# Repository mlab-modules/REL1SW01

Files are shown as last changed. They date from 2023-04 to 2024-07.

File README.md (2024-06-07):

# REL1SW01 - One Relay and/or Two N-MOSFET

## Introduction
The REL1SW01 is a versatile module from the MLAB series designed for triggering high current demaining devices (eg. high power led, high voltage circuits, DC motors, ..) using two N-MOSFET transistors or relay. It supports both bistable and monostable relay configurations and can be integrated into various electronic projects requiring relay switching or direct MOSFET control.

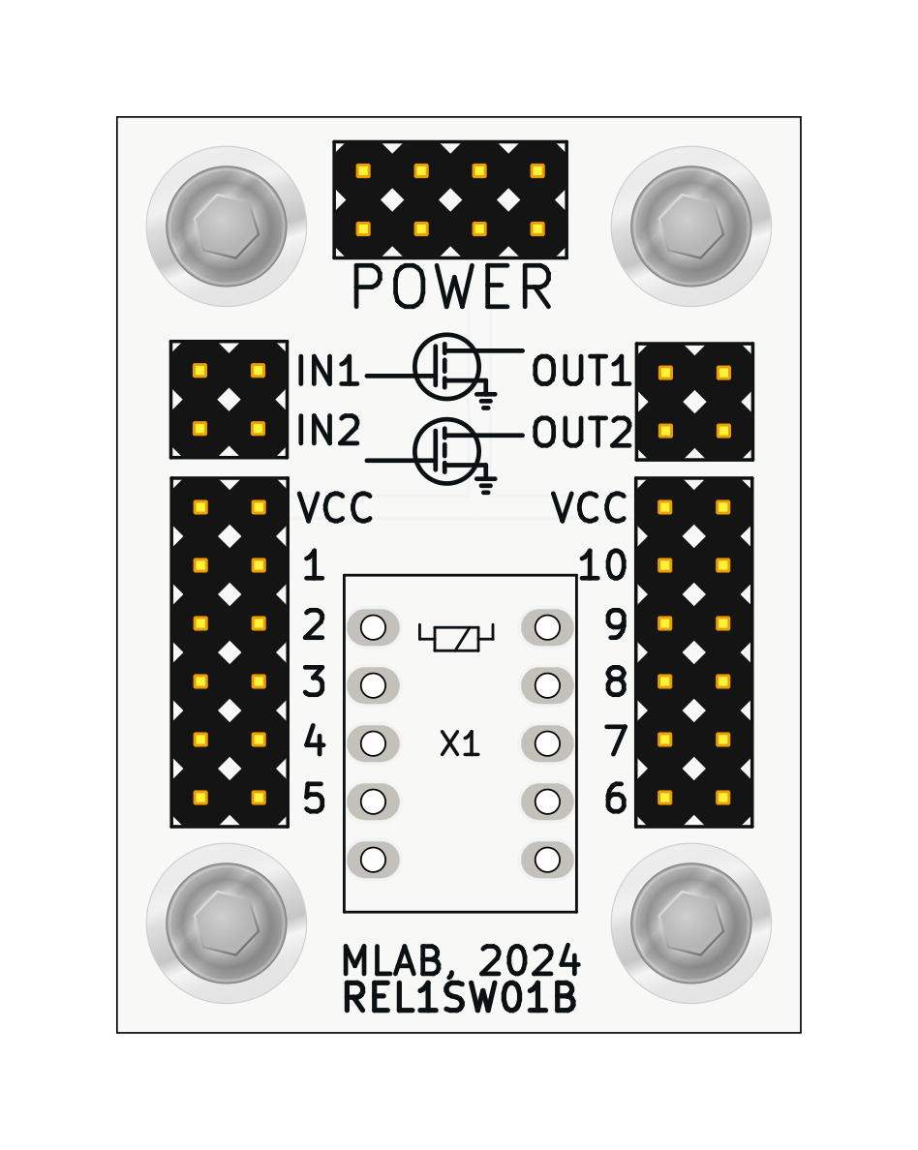
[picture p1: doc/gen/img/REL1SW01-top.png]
REL1SW01A


## Features
- Equipped with two N-MOSFET transistors (IRLML6244).
  - Capable of switching voltages up to 20V.
- Supports optional relay addition (e.g., DPDT FRT5).
- Configurable for either relay coil driving or independent transistor switching.
- Compatible with MCU control.

## Specifications
### MOSFET Transistors (IRLML6244)
- **Drain-Source Voltage (Vds):** 20V
- **Gate-Source Voltage (Vgs):** ±12V
- **Continuous Drain Current (Id):** 6.3A
- **Total Power Dissipation (Pd):** 1.3W
- **Gate Threshold Voltage (Vgs(th)):** 1.1V
- **On-State Resistance (Rds(on)):** 21mΩ at Vgs = 4.5V

## Usage
### Without Relay
- Connect the load to the drain of the MOSFET.
- The source of the MOSFET should be connected to GND.
- Use the gate to control switching via the MCU.

### With Relay
- Connect the relay's coil terminals to the MOSFETs as per the required configuration.
- The relay contacts will then be used to switch the external load.

## Configuration
To configure the module for different uses:
1. For direct MOSFET switching, connect the load between the drain and the positive supply (VCC).
2. For relay operation, connect the relay coil to the designated pins controlled by the MOSFETs.

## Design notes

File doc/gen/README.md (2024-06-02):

# PCB

Board size: 29.97x40.13 mm (1.18x1.58 inches)

- This is the size of the rectangle that contains the board
- Thickness: 1.6 mm (63 mils)
- Material: FR4
- Finish: HAL
- Layers: 2
- Copper thickness: 35 µm

Solder mask: TOP / BOTTOM

- Color: Green

Silk screen: TOP / BOTTOM

- Color: White

# Important sizes

Clearance: 0.15 mm (6 mils)

Track width: 0.5 mm (20 mils)

- By design rules: 0.0 mm (0 mils)

Drill: 1.0 mm (39 mils)

- Vias: N/A mm (N/A mils) [Design: 0.4 mm (16 mils)]
- Pads: 1.0 mm (39 mils)
- The above values are real drill sizes, they add 0.1 mm (4 mils) to plated holes (PTH)

Via: N/A/N/A mm (N/A/N/A mils)

- By design rules: 0.5/0.3 mm (20/12 mils)
- Micro via: yes [0.2/0.1 mm (8/4 mils)]
- Buried/blind via: yes
- Total: 0 (thru: 0 buried/blind: 0 micro: 0)

Outer Annular Ring: 0.25 mm (10 mils)

- By design rules: 0.25 mm (10 mils)

Eurocircuits class: 6A
- Using min drill 1.0 mm for an OAR of 0.25 mm

# General stats

Components count: (SMD/THT)

- Top: 0/10 (THT)
- Bottom: 12/0 (SMD)

Defined tracks:

- 0.25 mm (10 mils)
- 0.5 mm (20 mils)

Used tracks:

- 0.5 mm (20 mils) (14) defined: yes
- 0.8 mm (31 mils) (56) defined: no

Defined vias:

Used vias:

Holes (excluding vias):

- 0.89 mm (35 mils) (40)
- 1.0 mm (39 mils) (10)
- 3.0 mm (118 mils) (4)

Oval holes:

Drill tools (including vias and computing adjusts and rounding):

- 1.0 mm (39 mils) (40)
- 1.1 mm (43 mils) (10)
- 3.1 mm (122 mils) (4)

Solder paste stats:

Using a paste with 87.75 % alloy, that has an specific gravity for the alloy of 7.4 g/cm³
and 1.0 g/cm³ for the flux. This paste has an specific gravity of  4.15 g/cm³.

The stencil thickness is  0.12 mm.

| Side | Pads with paste | Area [mm²] | Paste [g] |
|---|---|---|---|
| Total  | 26 | 57.29 | 0.29 |

Note: this is just an approximation to the theoretical value. Margins of the solder mask and waste aren't computed.

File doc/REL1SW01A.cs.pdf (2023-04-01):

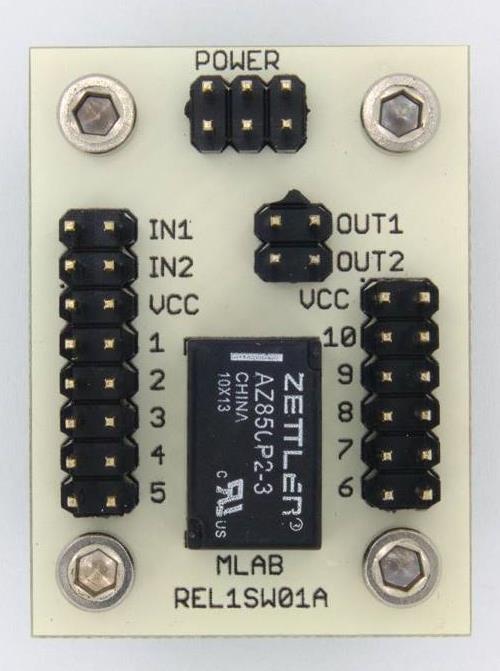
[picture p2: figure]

REL1SW01A / 2016-03-09 / jacho / http://www.mlab.cz | 1 / 4
REL1SW01A | MLAB

# Relé se dvěma tranzsitory

Jan Chroust

### Modul je určen pro spínání relé pomocí procesoru, nebo je možné

využít samostatně dva NMOSFETy.

# 1. Technické parametry

Parametr | Hodnota | Poznámka
Napájení | Dle relé | (Relé A-5V, AZ850 + další)
Využití | 1xrelé, 2xNMOSFET
Rozměry | 29.97 x 40.13 x 16 mm | Výška nad základní deskou

REL1SW01A | MLAB

# 2. Popis konstrukce

## 2.1. Úvod

Modul byl navržen jako univerzální patice pro jedno relé (je možné osadit relé řady A-5V, AZ850 + další pasující). Dva tranzistory umožňují ovládat až dvě cívky procesorem. Je možné využít modul jen jako tranzistorový spínač.

## 2.2. Zapojení

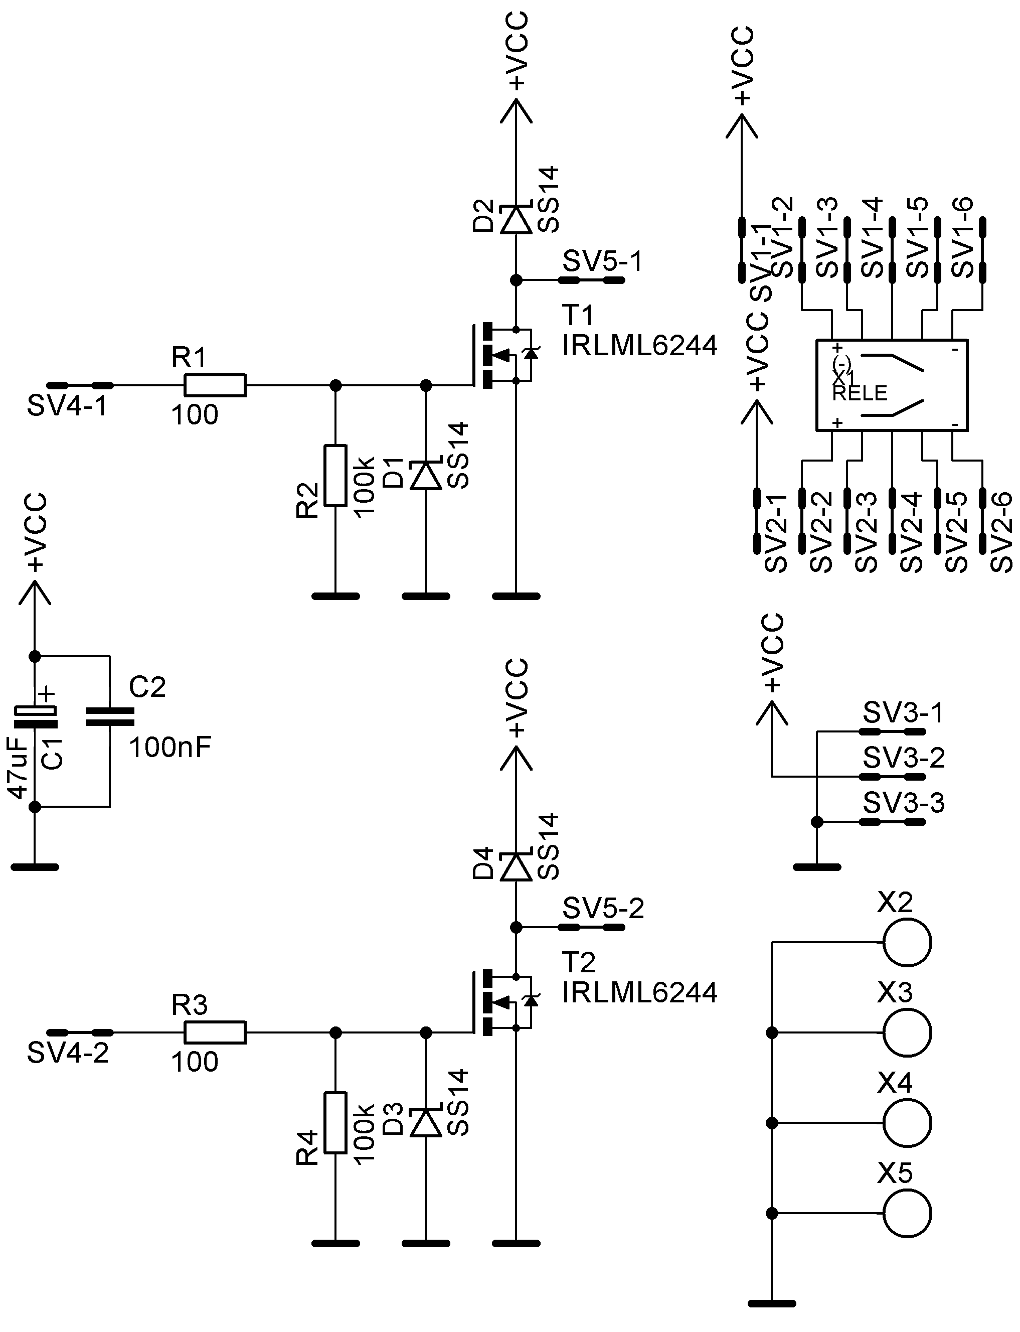
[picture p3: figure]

REL1SW01A | MLAB

# 3. Osazení a oživení

## 3.1. Osazení

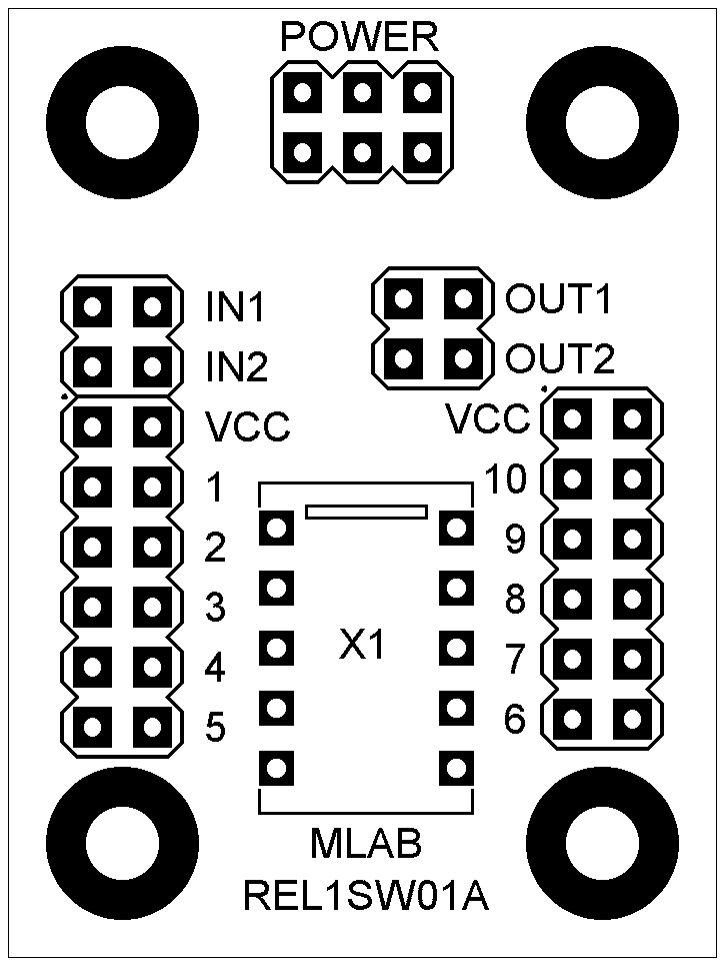
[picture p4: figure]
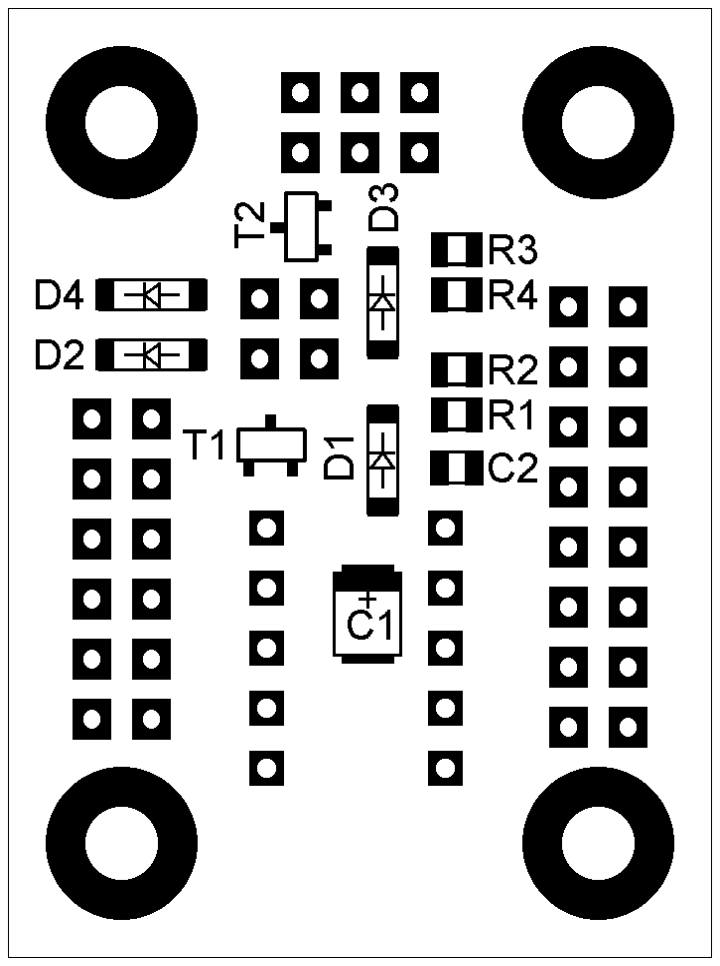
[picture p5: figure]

Označení | Typ (pouzdro)
C1 | 47uF (B)
C2 | 100nF (0805)
D1 - D4 | SS14 (SMA)
R1 ,R3 | 100 (0805)
R2, R4 | 100k (0805)
SV1, SV2 | JUMP2X6
SV3 | JUMP2X3
SV4, SV5 | JUMP2X2
T1, T2 | IRLML6244 (SOT23)
X1 | AZ850P2-3
X2 - X5 | Šroub M3

## 3.2. Oživení

Po osazení modulu je dobré provést vizuální kontrolu, případně proměřit, zda na napájení není zkrat. Další oživení není potřeba.

REL1SW01A | MLAB

Popis základního zapojení modulu s relé AZ850P2-3 (bistabilní) pro připojení k procesoru:
- připojte napájení na hřebínek POWER (Pro AZ850P2-3 stačí 3V)
- mínus pól (pin 5 pro AZ850P2) nastavovací cívky propojte vodičem na OUT1
- mínus pól (pin 6 pro AZ850P2) resetovací cívky propojte vodičem na OUT2
- kladný pól (pin 1 pro AZ850P2) nastavovací cívky propojte vodičem na VCC
- kladný pól (pin 10 pro AZ850P2) resetovací cívky propojte vodičem na VCC
- řídící signály se přivádějí na IN1 (pro nastavovací cívku u AZ850P2-3) a IN2 (pro resetovací cívku u AZ850P2-3)
- Přivedením kladného pulzu na IN1 dojde k přepnutí relé do jedné polohy. Pro přepnutí do druhé polohy se přivede kladný pulz na IN2. (Relé AZ850P2-3 je bistabilní. To znamená, že pro udržení polohy relé, není potřeba udržovat napětí na cívce.)

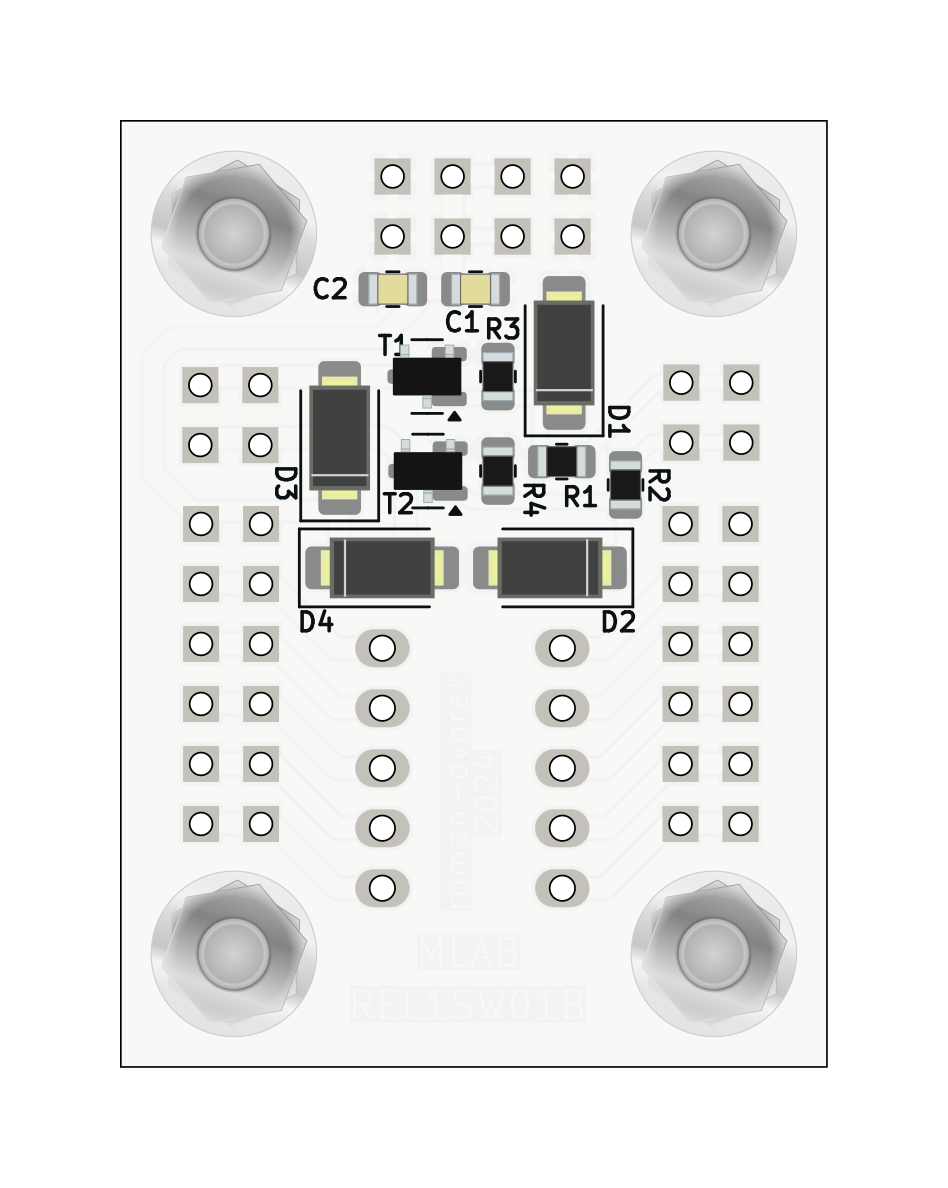
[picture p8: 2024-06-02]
doc/gen/img/REL1SW01-bottom.png

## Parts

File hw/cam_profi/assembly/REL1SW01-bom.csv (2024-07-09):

Component | Description | Part | References | Value | Footprint | Quantity Per PCB | Datasheet | ust_id
1 | Unpolarized capacitor, small symbol | C_Small | C2 | 100nF | C_0805_2012Metric | 1 | ~ | 5c70984712875079b91f8b4c
2 | Unpolarized capacitor, small symbol | C_Small | C1 | 47uF | C_0805_2012Metric | 1 | ~ | 60d580ff1287500165f8595a
3 | 40V 1A Schottky Diode, SMA | SS14 | D1D2D3D4 | SS14 | D_SMA | 4 | https://www.vishay.com/docs/88746/ss12.pdf | 5c70984512875079b91f88bd
4 |  | R0805 | R1R2 | 100R | R_0805_2012Metric | 2 |  | 5c70984512875079b91f8977
5 |  | R0805 | R3R4 | 100k | R_0805_2012Metric | 2 |  | 639ed3d540d28a66c9e88a9e
6 |  | IRLML6244TRPBF | T1T2 | IRLML6244 | SOT-23 | 2 |  | 5c70984712875079b91f8aef
7 |  | RELE | X1 | RELE | Relay_DPDT_FRT5 | 1

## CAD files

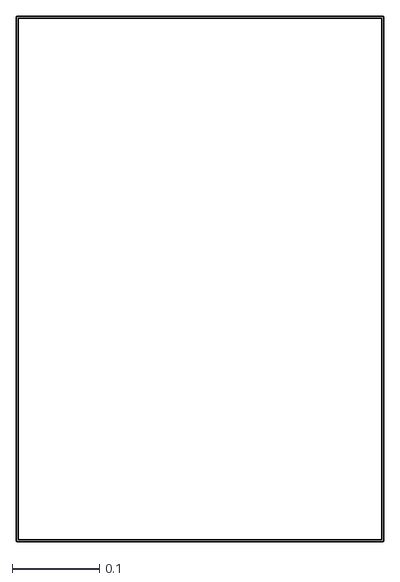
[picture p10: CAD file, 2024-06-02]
doc/gen/dxf/REL1SW01-F_Courtyard.dxf
0.421 x 0.602

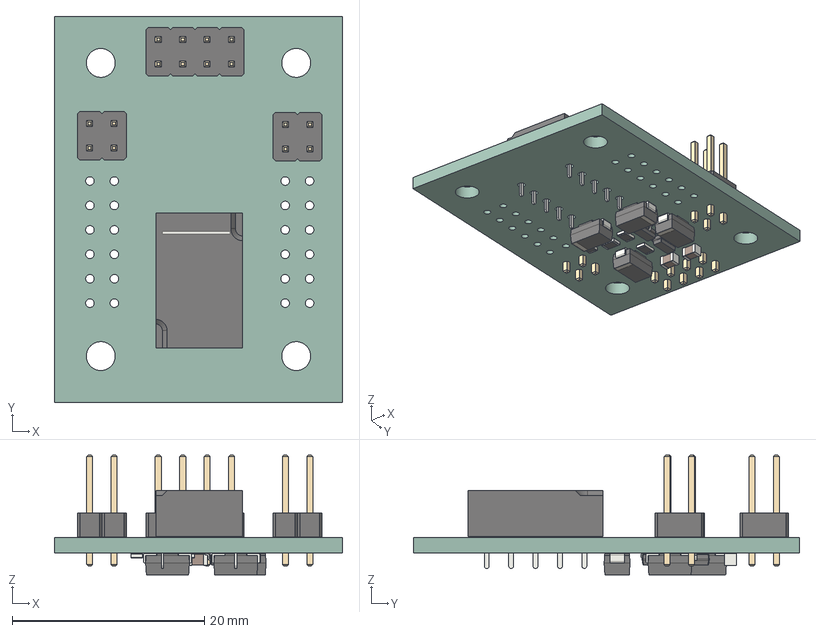
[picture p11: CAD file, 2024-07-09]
doc/gen/REL1SW01.step
30.0 x 40.1 x 12.5 mm
Relay_DPDT_FRT5
PinHeader_2x04_P254mm_Vertical
PinHeader_2x02_P254mm_Vertical x 2
R_0805_2012Metric x 4
SOT_23 x 2
D_SMA x 4
C_0805_2012Metric x 2
kibot_hpxaq1g5 PCB

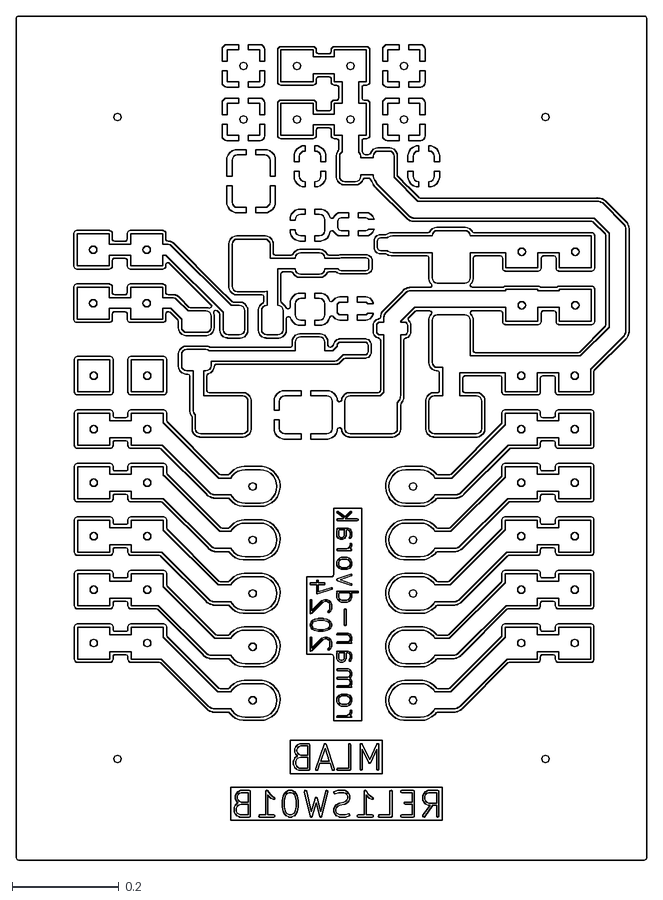
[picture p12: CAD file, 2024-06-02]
doc/gen/dxf/REL1SW01-B_Cu.dxf
1.18 x 1.58

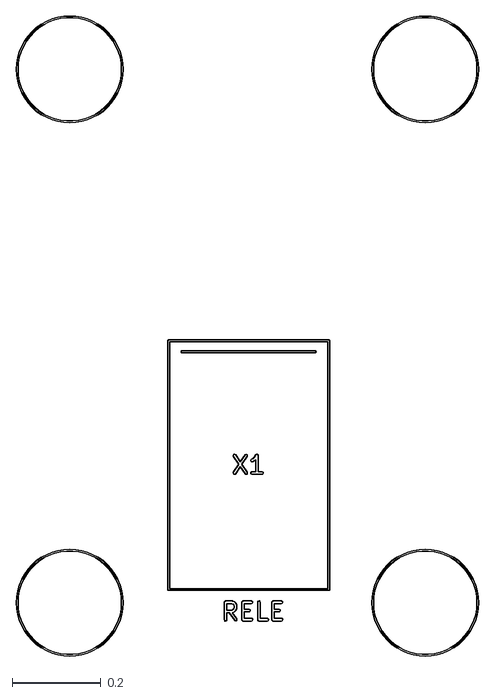
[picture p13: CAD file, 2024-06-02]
doc/gen/dxf/REL1SW01-F_Fab.dxf
1.04 x 1.44

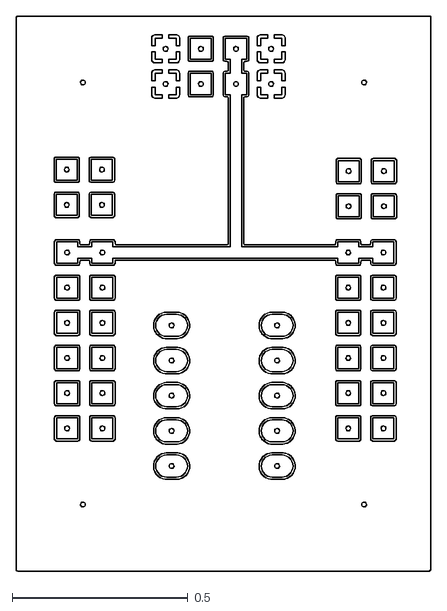
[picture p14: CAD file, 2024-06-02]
doc/gen/dxf/REL1SW01-F_Cu.dxf
1.18 x 1.58

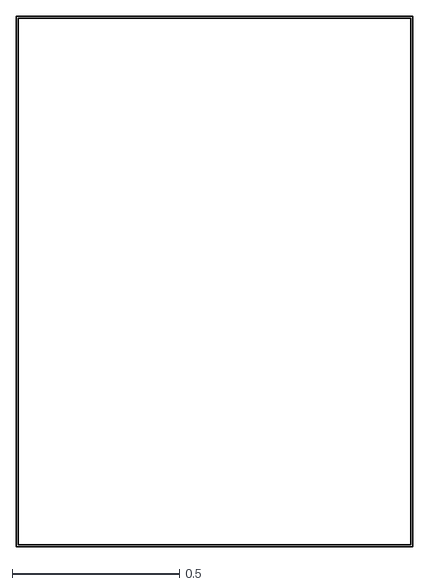
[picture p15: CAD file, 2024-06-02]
doc/gen/dxf/REL1SW01-Edge_Cuts.dxf
1.19 x 1.59

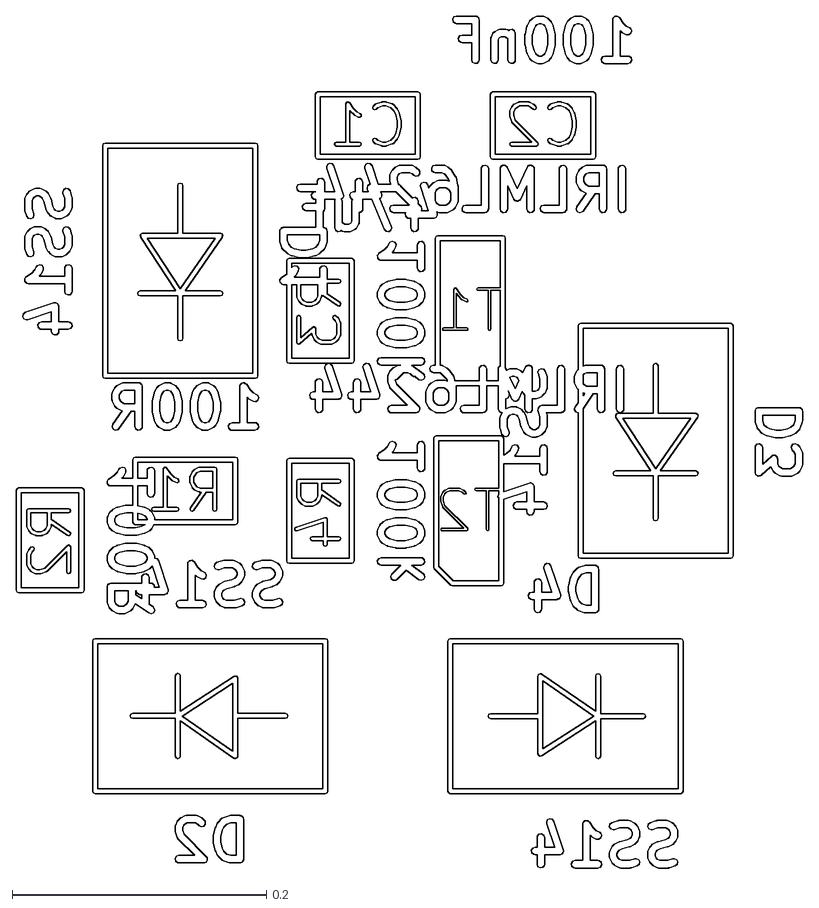
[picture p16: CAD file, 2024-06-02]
doc/gen/dxf/REL1SW01-B_Fab.dxf
0.619 x 0.67

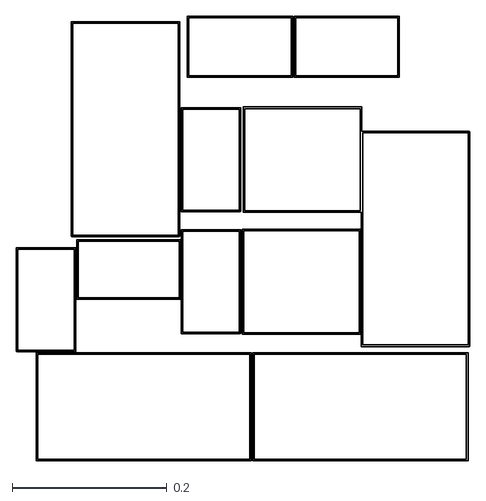
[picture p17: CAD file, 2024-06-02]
doc/gen/dxf/REL1SW01-B_Courtyard.dxf
0.585 x 0.574

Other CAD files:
doc/gen/dxf/REL1SW01-User_3.dxf
doc/gen/dxf/REL1SW01-Margin.dxf
doc/gen/dxf/REL1SW01-User_7.dxf
doc/gen/dxf/REL1SW01-User_4.dxf
doc/gen/dxf/REL1SW01-User_6.dxf
doc/gen/dxf/REL1SW01-User_9.dxf
doc/gen/dxf/REL1SW01-User_2.dxf
doc/gen/dxf/REL1SW01-User_5.dxf
doc/gen/dxf/REL1SW01-User_Comments.dxf
doc/gen/dxf/REL1SW01-F_Adhesive.dxf
doc/gen/dxf/REL1SW01-B_Adhesive.dxf
doc/gen/dxf/REL1SW01-B_Mask.dxf
doc/gen/dxf/REL1SW01-B_Paste.dxf
doc/gen/dxf/REL1SW01-B_Silkscreen.dxf
doc/gen/dxf/REL1SW01-F_Mask.dxf
doc/gen/dxf/REL1SW01-F_Paste.dxf
doc/gen/dxf/REL1SW01-F_Silkscreen.dxf
doc/gen/dxf/REL1SW01-User_1.dxf
doc/gen/dxf/REL1SW01-User_8.dxf
doc/gen/dxf/REL1SW01-User_Drawings.dxf
doc/gen/dxf/REL1SW01-User_Eco1.dxf
doc/gen/dxf/REL1SW01-User_Eco2.dxf

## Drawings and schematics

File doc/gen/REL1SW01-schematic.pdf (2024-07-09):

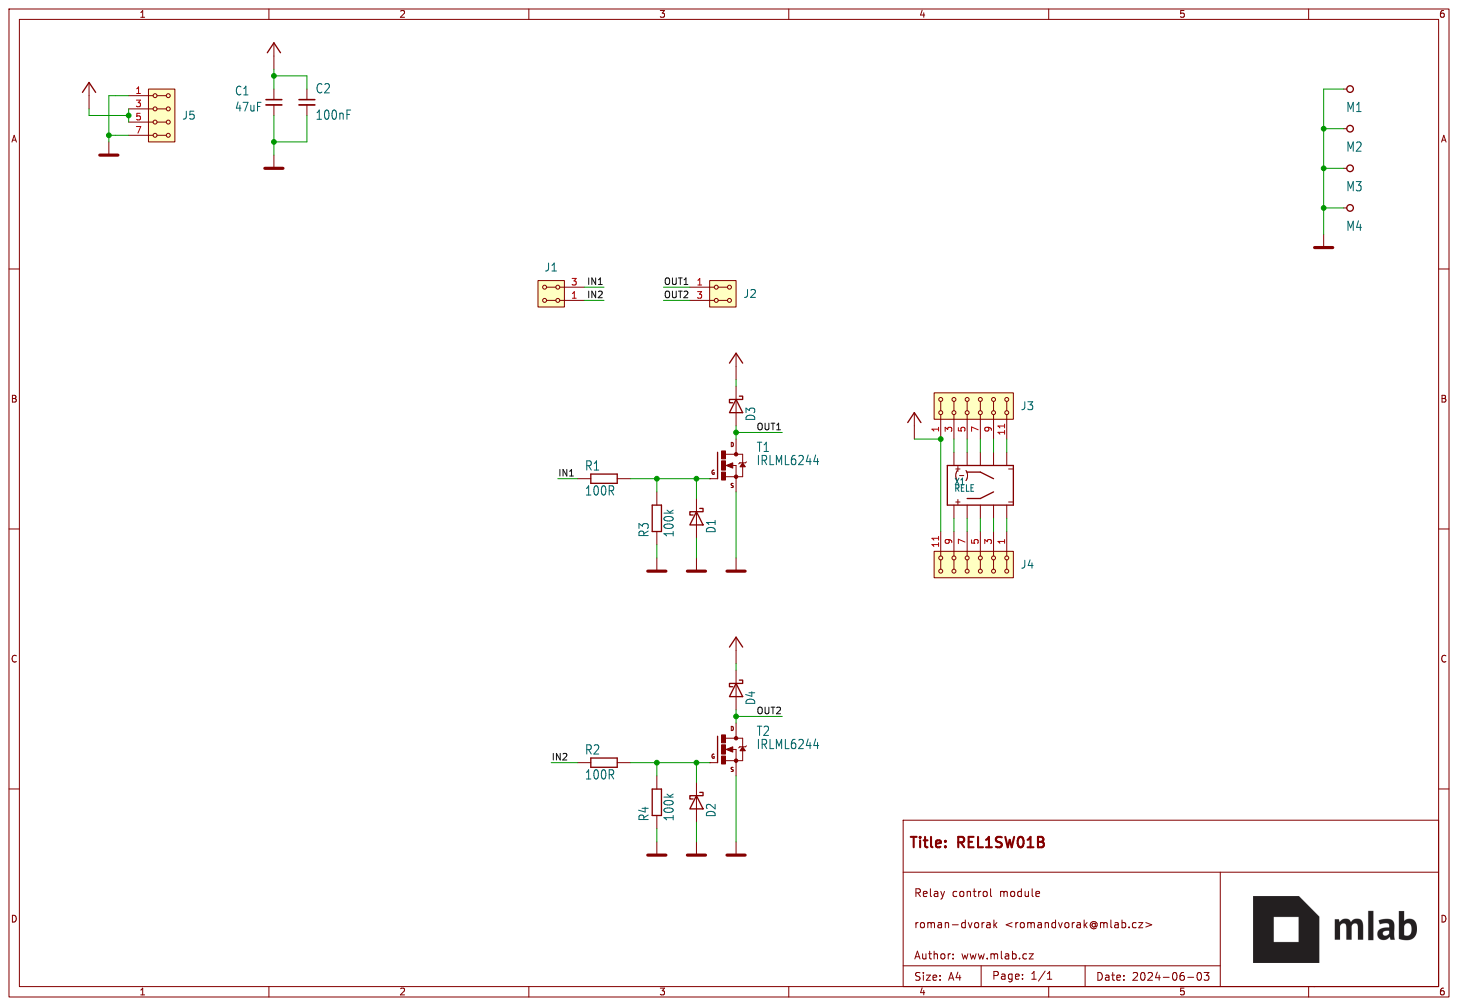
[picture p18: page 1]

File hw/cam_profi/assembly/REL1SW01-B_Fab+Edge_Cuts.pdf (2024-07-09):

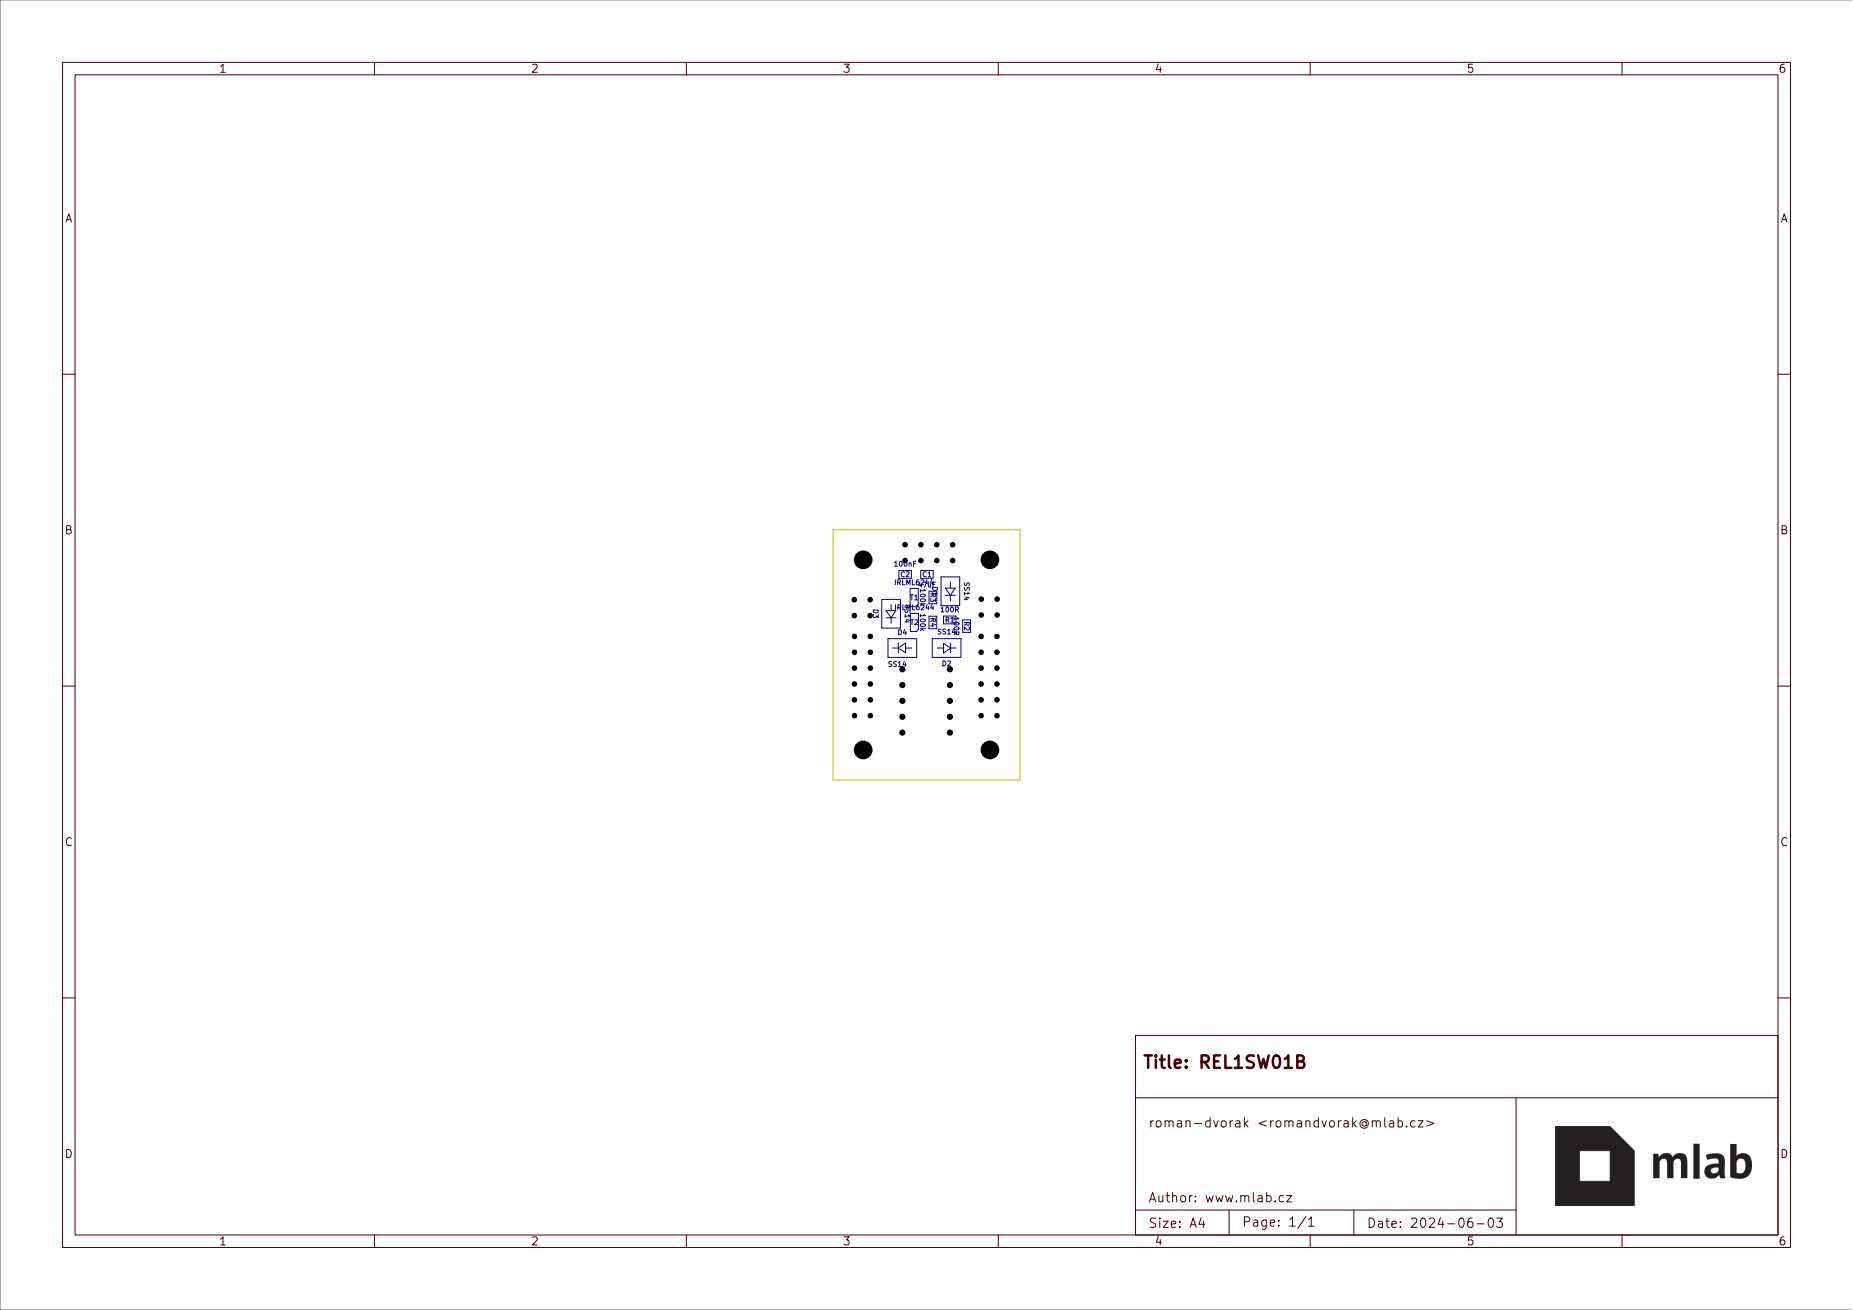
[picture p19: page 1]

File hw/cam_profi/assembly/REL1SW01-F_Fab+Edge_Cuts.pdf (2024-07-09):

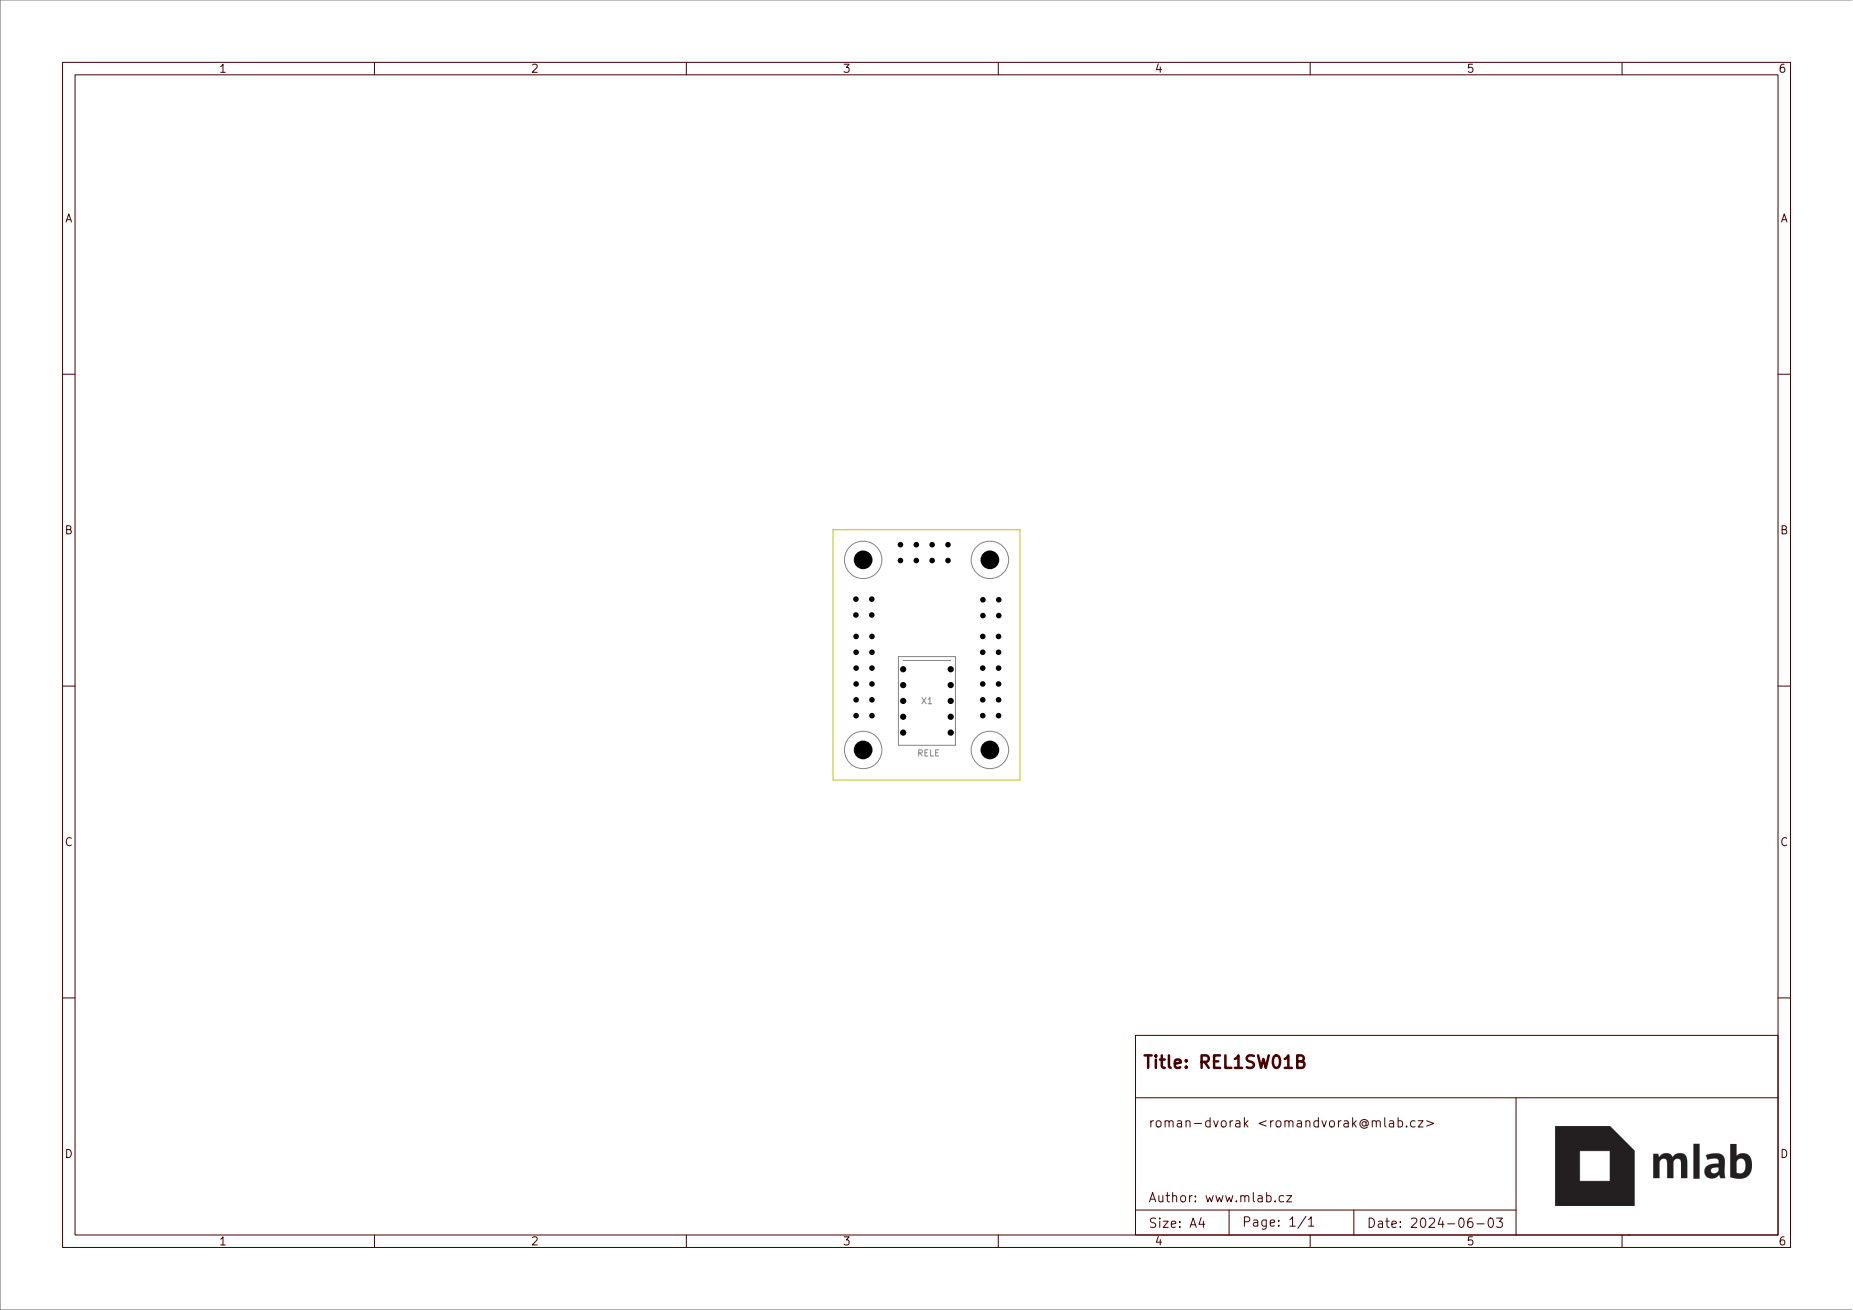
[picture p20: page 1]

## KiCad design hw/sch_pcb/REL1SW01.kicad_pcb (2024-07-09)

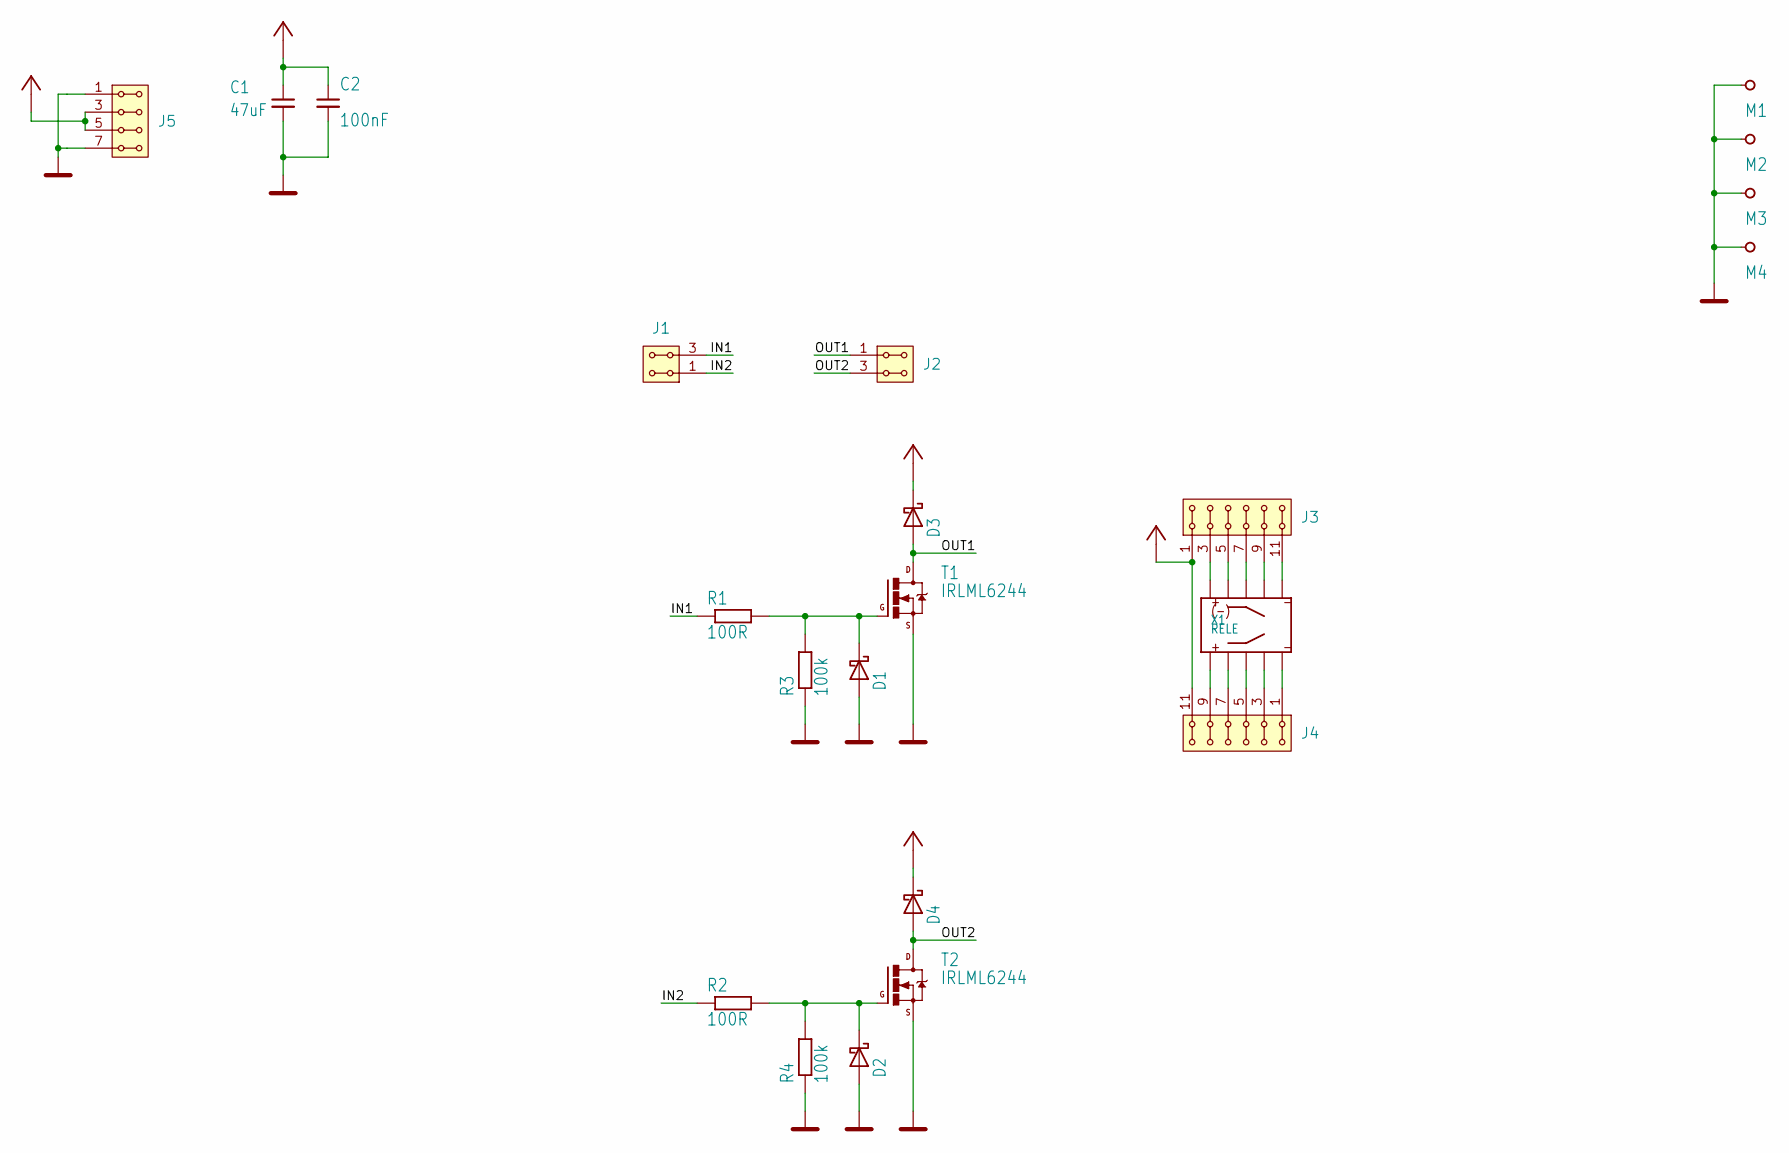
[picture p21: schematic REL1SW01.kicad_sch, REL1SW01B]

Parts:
C1: 47uF; C_0805_2012Metric
C2: 100nF; C_0805_2012Metric
D1, D2, D3, D4: SS14; D_SMA
J1, J2: HEADER_2x02_PARALLEL; Straight_2x02
J3, J4: HEADER_2x06_PARALLEL; Straight_2x06
J5: HEADER_2x04_PARALLEL; Straight_2x04
M1, M2, M3, M4: SROUB3M; MountingHole_3mm
R1, R2: 100R; R_0805_2012Metric
R3, R4: 100k; R_0805_2012Metric
T1, T2: IRLML6244; SOT-23
X1: RELE; Relay_DPDT_FRT5

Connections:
+VCC: C1.1, C2.1, D3.1 (K), D4.1 (K), J3.1, J3.2, J4.11, J4.12, J5.3, J5.4, J5.5, J5.6
/IN1: J1.3, J1.4, R1.1
/IN2: J1.1, J1.2, R2.1
/OUT1: D3.2 (A), J2.1, J2.2, T1.3 (D)
/OUT2: D4.2 (A), J2.3, J2.4, T2.3 (D)
GND: C1.2, C2.2, D1.2 (A), D2.2 (A), J5.1, J5.2, J5.7, J5.8, M1.1, M2.1, M3.1, M4.1, R3.1, R4.1, T1.2 (S), T2.2 (S)
unnamed: D1.1 (K), R1.2, R3.2, T1.1 (G)
unnamed: D2.1 (K), R2.2, R4.2, T2.1 (G)
unnamed: J4.9, J4.10, X1.1
unnamed: J4.7, J4.8, X1.2
unnamed: J4.5, J4.6, X1.3
unnamed: J4.3, J4.4, X1.4
unnamed: J4.1, J4.2, X1.5
unnamed: J3.11, J3.12, X1.6
unnamed: J3.9, J3.10, X1.7
unnamed: J3.7, J3.8, X1.8
unnamed: J3.5, J3.6, X1.9
unnamed: J3.3, J3.4, X1.10

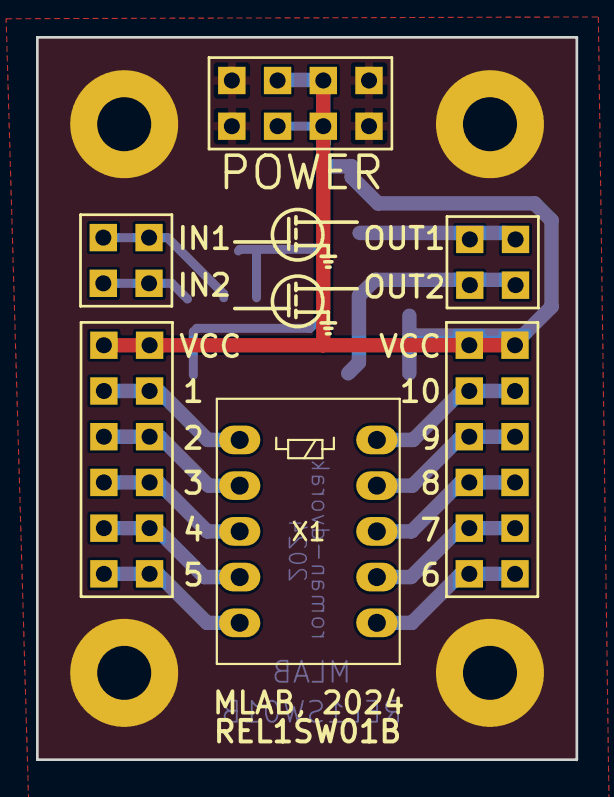
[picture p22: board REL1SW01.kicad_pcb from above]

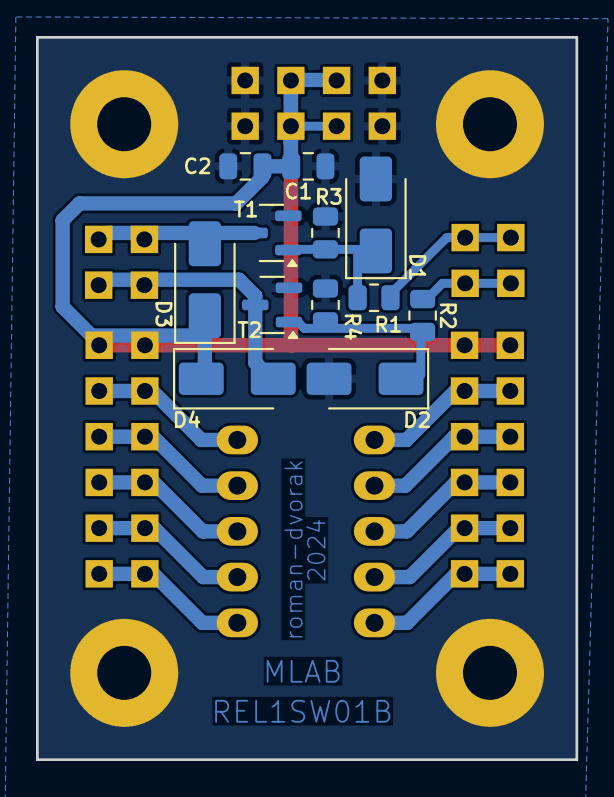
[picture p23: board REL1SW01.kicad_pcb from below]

Board: 2 copper layers, 30.0 x 40.1 mm, 22 parts (12 on the bottom side), 18 nets.

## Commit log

2023-04-01 Adding force option to enable splitting in not fresh copy of Modules repository.
    [untitled.brd, untitled.sch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]
2024-06-02 Transfer to kicad
    [REL1SW01.kicad_pcb, REL1SW01.kicad_sch, untitled.brd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]
2024-06-02 Update actions products
    [REL1SW01-B_Adhesive.dxf, REL1SW01-B_Courtyard.dxf, REL1SW01-B_Cu.dxf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]
2024-06-02 update template
    [REL1SW01.kicad_pcb, REL1SW01.kicad_sch]
2024-06-02 layout improvements
    [REL1SW01.kicad_pcb, REL1SW01.kicad_sch]
2024-06-06 Use relative path to title blocks.
    [REL1SW01.kicad_sch]
2024-07-09 add ust id
    [REL1SW01.kicad_pcb, REL1SW01.kicad_sch]
